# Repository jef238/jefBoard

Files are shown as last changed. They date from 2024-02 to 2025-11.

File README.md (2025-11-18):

# jefBoard
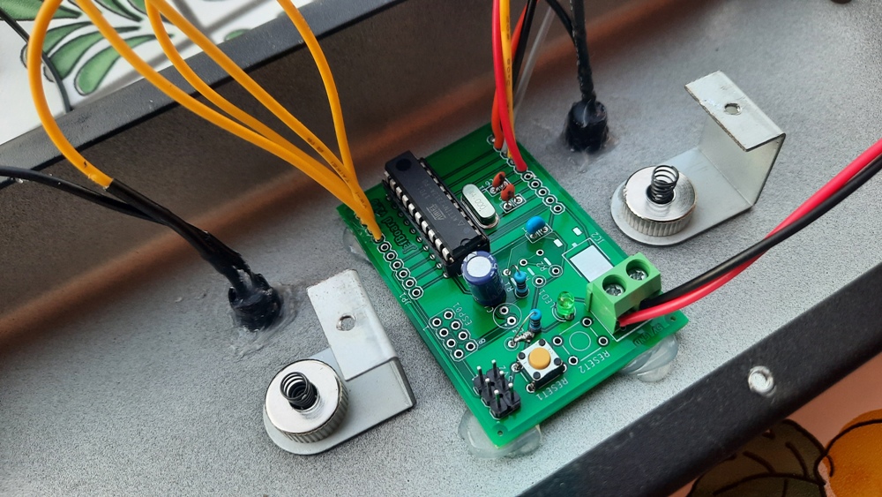
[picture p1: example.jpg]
example

## Cos'è

JefBoard è una scheda di sviluppo basata sul microcontroller Attiny2313 della ATMEL. Si presta allo sviluppo di applicazioni di varia natura e integra la predisposizione per la scheda WiFI ESP-01 (Opzionale) e il connettore per la programmazione ISP dell'Attiny2313.
Alcune caratteristiche:
- JefBoard espone tutti i pin dell'Attiny2313 per il loro utilizzo.
- JefBoard permette la realizzazione di applicazioni con supporto WiFi (il modulo ESP-01 comunica tramite connessione seriale con l'Attiny2313).
- JefBoard può essere assemblata anche senza l'ESP-01 e relativi componenti di alimentazione se non si necessita di supporto WiFi abbassando ulteriormente il costo.
- JefBoard è una scheda di piccole dimensioni 6x4 cm.

## Attiny 2313 pinout

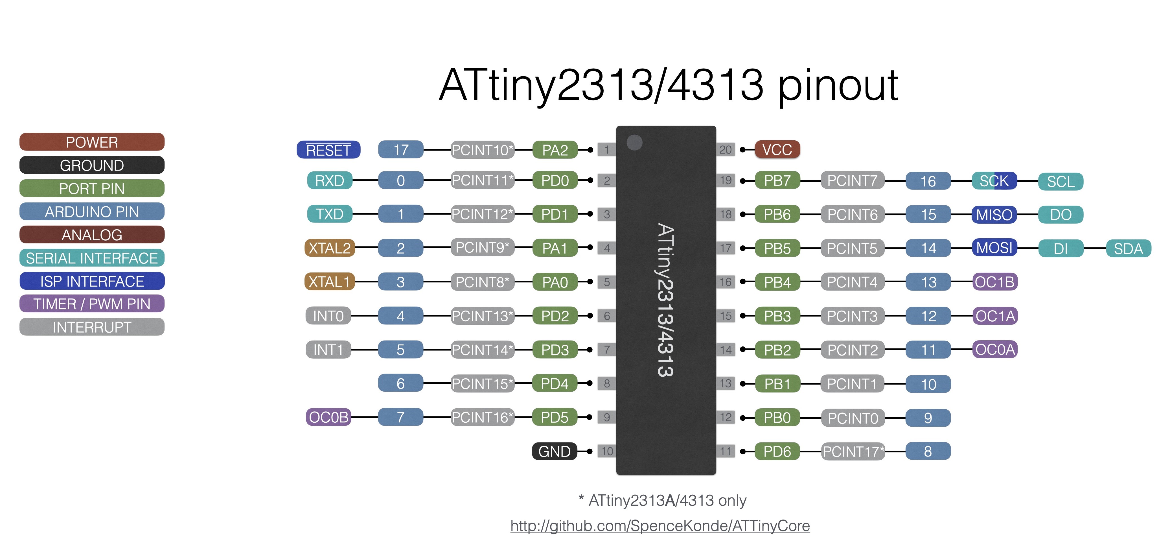
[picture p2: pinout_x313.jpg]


# Schema ed elenco componenti

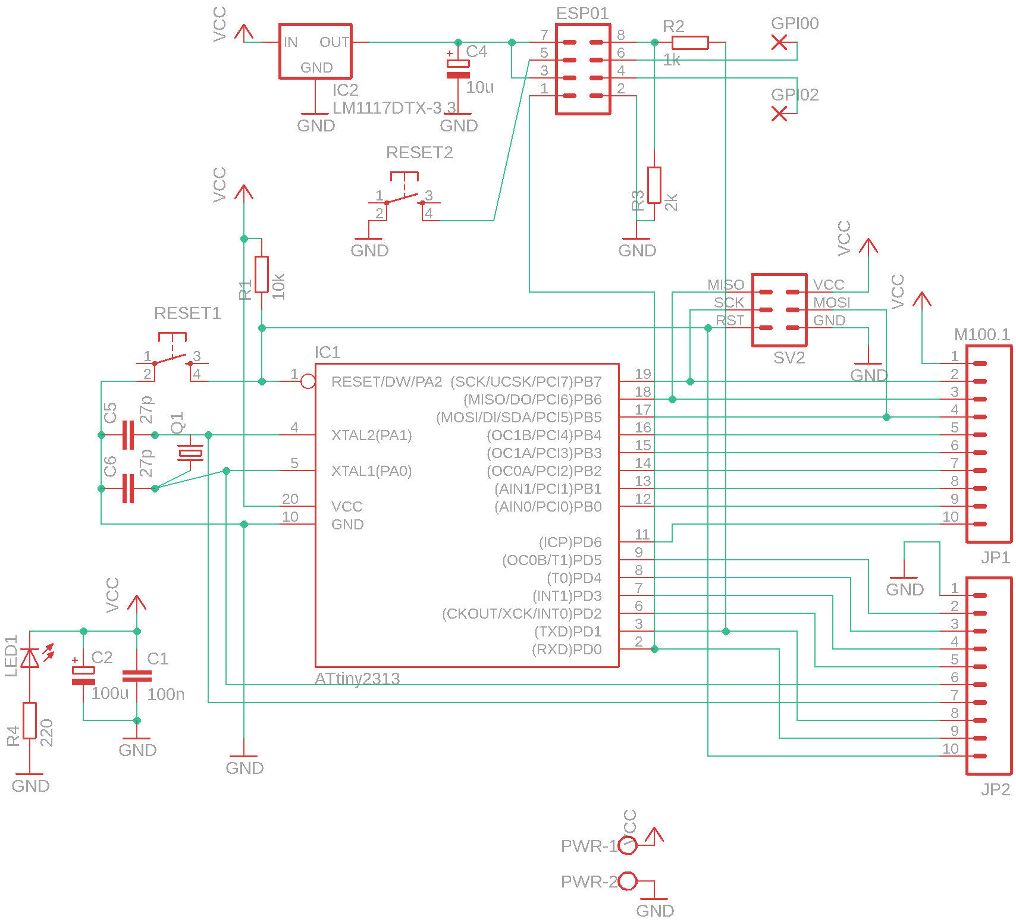
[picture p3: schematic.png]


# PCB Layout
Per reperire la PCB scrivi al mio indirizzo giuseppe.culotta@gmail.com

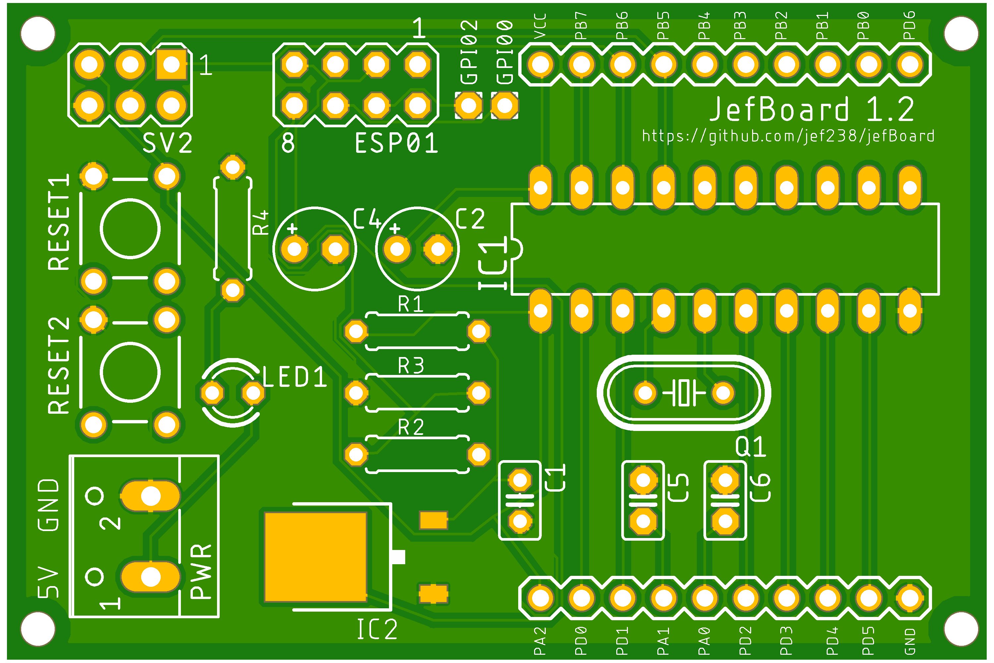
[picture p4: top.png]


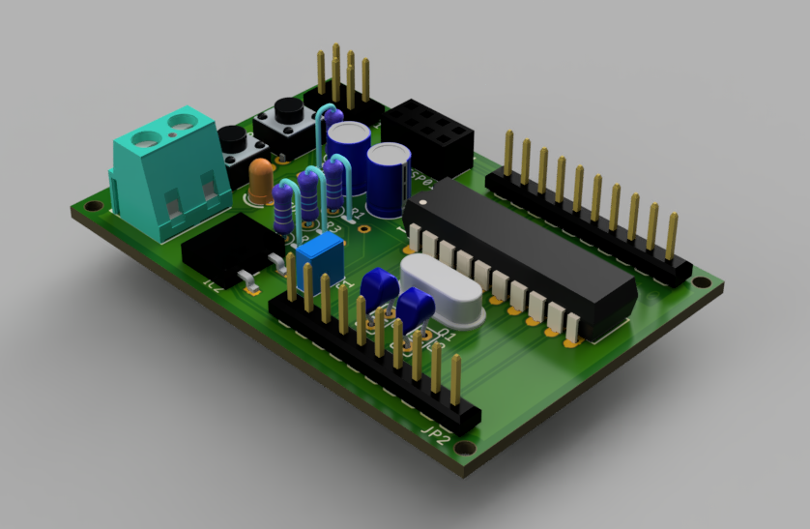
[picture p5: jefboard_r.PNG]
jefboard_r


## Elenco componenti

| Sigla | Valore | Tipo			 | Note |
|---|---|---|---|
| C1 | 100n 		| Condensatore poliestere |				 | 
| C2 | 100u 		| Condensatore elettrolitico |					 |
| C4 | 10u 		| Condensatore elettrolitico | (Opzionale - Solo in caso di supporto WIFI) |	
| C5 | 22p 		| Condensatore ceramico |					 |
| C6 | 22p 		| Condensatore ceramico | 					 |
| ESP01 | 		| Connettore pin		| (Opzionale - Solo in caso di supporto WIFI) |
| IC1 | ATtiny2313/ATtiny2313a | AVR			 |				 |
| IC2 | LM1117DTX 3.3V 		|			 | (Opzionale - Solo in caso di supporto WIFI) |	
| JP1 | 		| Connettore tipo M100.1	| (Opzionale) 		 |
| JP2 | 		| Connettore tipo M100.1	| (Opzionale) |
| LED1  | 		| LED3MM |				 |
| PWR | 		| Connettore tipo W237-102 | (Opzionale) |
| Q1 | 		| Quarzo 4MHZ 	 |	 |
| R1 | 10k 		| 1/4w		 | |
| R2 | 1k 		| 1/4w 				| (Opzionale - Solo in caso di supporto WIFI) |	
| R3 | 2k 		| 1/4w 	 		| (Opzionale - Solo in caso di supporto WIFI) |	
| R4 | 220 		| 1/4w 		| 					 |
| RESET1| 		| Microswitch | |
| RESET2| 		| Microswitch			| (Opzionale - Solo in caso di supporto WIFI) |
| SV2 | 		| Connettore pin | |
         
# Programmazione

Io utilizzo Xcode e [CrossPack for AVR Development](https://github.com/obdev/CrossPack-AVR) in ambiente Mac.

In ambiente Windows vi consiglio di utilizzare Atmel Studio 7 ma sembra che recentemente sia stato sostituito da un altro prodotto: https://www.microchip.com/en-us/tools-resources/develop/microchip-studio.
Se utilizzate Atmel Studio ricordate di selezionare l'Attiny2313a come chip durante la creazione del progetto ed eseguire i seguenti step:
- Project->Properties->Toolchain->AVR/GNU C Compiler->Symbols: aggiungere F_CPU=2000000  (In questo caso la frequenza di clock è di 2MHZ)
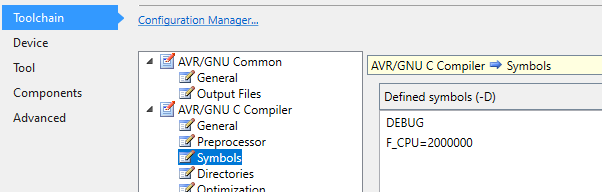
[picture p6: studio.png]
atstudio

- Impostare USBTINY come external tool (https://www.programming-electronics-diy.xyz/2020/09/using-usbtinyisp-programmer-with-atmel.html), in questo modo potete scrivere il firmware in formato hex sul chip direttamente dall'interfaccia di Atmel Studio dal menu Tools.

Come programmatore hardware per l'ISP ho utilizzato l'USBtinyISP:

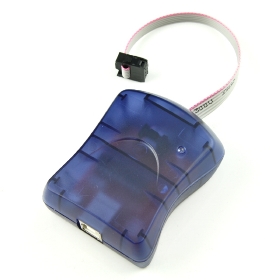
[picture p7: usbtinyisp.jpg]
usbtinyisp


## 1. Impostazione FUSE bits

Questa procedura deve essere eseguita solo una volta poichè serve a settare le impostazioni di base del bootloader del chip   

- Utilizzare AVR Calculator per ottenere la stringa corretta (http://www.engbedded.com/fusecalc)

    ESEMPI:
    ```
    /* Oscillatore interno 1MHZ */     						-U lfuse:w:0x64:m -U hfuse:w:0xdf:m -U efuse:w:0xff:m
    /* Quarzo esterno da 3 a 8MHZ */   						-U lfuse:w:0xfd:m -U hfuse:w:0xdf:m -U efuse:w:0xff:m
    /* Quarzo esterno da 16MHZ con CKDIV8 e frequenza effettiva 2MHZ */		-U lfuse:w:0x5e:m -U hfuse:w:0xdf:m -U efuse:w:0xff:m     
    ```
- Impostare i FUSE Bits nell'Attiny2313:
   ```
   avrdude -c usbtiny -p t2313 -e -U lfuse:w:0xfd:m -U hfuse:w:0xdf:m -U efuse:w:0xff:m
   ```

## 2a. Compilazione su Xcode (Mac)

- Modificare le righe seguenti nel file Makefile (ATTENZIONE: la riga FUSES deve essere identica alle impostazioni di FUSE Bits dell'Attiny2313; in questo esempio si utilizza un quarzo esterno da 4MHZ):
	```
	DEVICE     = attiny2313
	CLOCK      = 4000000
	PROGRAMMER = -c usbtiny -p attiny2313
	OBJECTS    = main.o
	FUSES      = -U lfuse:w:0xFD:m -U hfuse:w:0xDF:m -U efuse:w:0xFF:m -U lock:w:0xFF:m
  ```
- effettuare build (verrà generato main.hex)

## 2b. Compilazione su Atmel Studio (Windows)

- Menu Build->Build "nome progetto"
                                                             
## 3. Collegare l'USBtinyISP

- Assicurarsi di aver correttamente collegato il programmatore al computer e di aver installato i driver per il suo funzionamento (su Mac non è necessario installare driver)

- Collegare l'USBtinyISP al connettore SV2

## 4a. Flash su Mac

- Caricare il file .hex nel chip: 
   ```
   avrdude -c usbtiny -p t2313 -e -U flash:w:main.hex
   ```
## 4b. Flash su Windows (Atmel Studio)

- Menu Tools->USBTiny (per la configurazione vedi https://www.programming-electronics-diy.xyz/2020/09/using-usbtinyisp-programmer-with-atmel.html)

# Utilizzo dell'ESP01 per il supporto WIFI

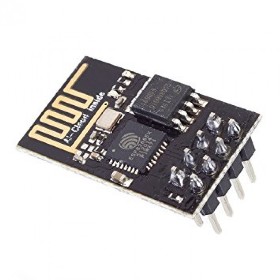
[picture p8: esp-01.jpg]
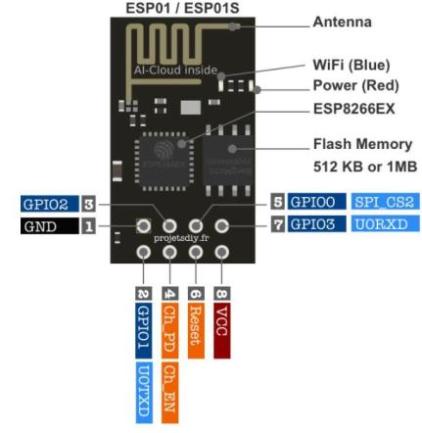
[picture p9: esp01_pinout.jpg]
  

L'ESP01 è un modulo SOC basato sul chip ESP8266 che permette di aggiungere il supporto al WIFI in modo semplice ed economico.
Prima di inserirlo sulla jefBoard è necessario fare una precisazione:
L'ESP01 viene fornito generalmente con un firmware dotato di soli comandi AT per cui prima di utilizzarlo nei nostri progetti è necessario caricare il firmware nodeMCU (https://it.wikipedia.org/wiki/NodeMCU). Con questo firmware è possibile programmare facilmente l'ESP01 tramite linguaggio LUA ed è possibile compilare una versione custom di nodeMCU con il supporto delle librerie/funzionalità necessarie in base all'utilizzo su https://nodemcu-build.com.

E' necessario inoltre dotarsi di un adattore USB seriale TTL:

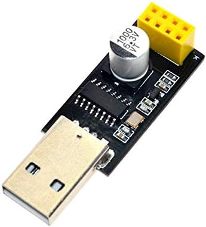
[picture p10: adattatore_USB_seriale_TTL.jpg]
adattatore


## Istruzioni per l’installazione di esptool su MACOSX:

- Scaricare e scompattare esptool (https://github.com/espressif/esptool)

- Assicurarsi di avere Python 1.7 o successivo installato sul sistema

- Spostarsi sulla directory appena scompattata ed eseguire:
   ```
   sudo python setup.py install
   ```

## Istruzioni per flash nodemcu su ESP01
Esistono tanti modi per abilitare la modalità flash su ESP-01 (una ricerca su google è altamente consigliata...). Tempo fa ho realizzato una scheda che per comodità mi permette di riavviare tramite reset l'ESP01 (pulsante 1) mentre metto a massa il pin GPIO0 (pulsante 2):

- Posizionare l’ESP01 e l’interfaccia seriale/USB sulla scheda di programmazione:

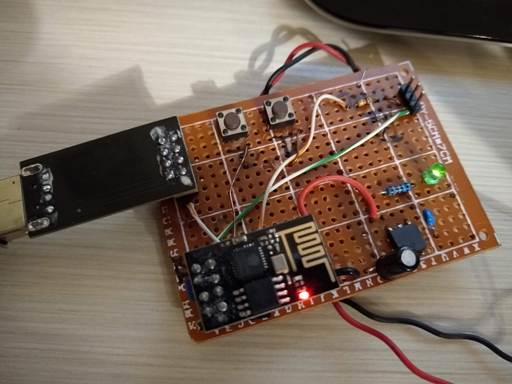
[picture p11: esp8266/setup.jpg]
  

- Per settare l’ESP01 in modalità flash tenere premuto il pulsante 2 e contemporaneamente effettuare un reset premendo e rilasciando il pulsante 1; dopo qualche istante rilasciare il pulsante 2.

- Effettuare il comando (nodemcu_base_int.bin è il nome del file del firmware nodemcu da flashare vedi cartella esp8266):
   ```  
   python esptool.py --port /dev/tty.wchusbserialfa140 write_flash 0x00000 nodemcu_base_int.bin
   ```
- (opzionale) restore firmware originale (11/12/2019)
   ``` 
   python esptool.py --port /dev/tty.wchusbserialfd130 write_flash 0x00000 v0.9.2.2\ AT\ Firmware.bin
   ``` 
## Programmazione ESP01 tramite script LUA
Una volta caricato il firmware nodeMCU è possibile caricare gli script LUA. Il file denominato init.lua viene caricato all'avvio in maniera automatica.
E' possibile utilizzare il software ESPlorer (https://github.com/4refr0nt/ESPlorer) sia per caricare sia gli script LUA che per gestire al meglio l'ESP01.

# Utilizzo di jefBoard come server WIFI
In questo caso l'ESP01 funge da server in ascolto sulla porta 8080 tramite connessione WIFI; Ricevuto il comando lo inoltra tramite la connessione seriale verso l'Attiny2313.
Per questo utilizzo è necessario che la scheda sia equipaggiata con l'ESP01 aggiornata con il firmware nodeMCU, ed i relativi componenti. Di seguito un esempio di file init.lua (da caricare sull'ESP01) e del codice da utilizzare sull'Attiny2313:

## init.lua (ESP01)

```
wifi.setmode(wifi.SOFTAP)
cfg={}
cfg.ssid="jefBoard"
wifi.ap.config(cfg)

uart.setup(0, 9600, 8, uart.PARITY_NONE, uart.STOPBITS_1, 1)

sv = net.createServer(net.TCP, 30)

function receiver(sck, data)
  print(data)  --senda data to jefBoard by serial
end

if sv then
  sv:listen(8080, function(conn)
    conn:on("receive", receiver)    
  end)
end
```

## main.c (jefBoard/Attiny2313)

```
#define F_CPU 4000000 UL // 4 MHz Crystal

#include <avr/io.h>
#include <util/delay.h>
#include <avr/interrupt.h>

// Define baud rate
#define USART_BAUDRATE 9600
#define BAUD_PRESCALE (((F_CPU / (USART_BAUDRATE * 16UL))) - 1)

volatile unsigned char value;
/* This variable is volatile so both main and RX interrupt can use it.
 It could also be a uint8_t type */

/* Interrupt Service Routine for Receive Complete
 NOTE: vector name changes with different AVRs see AVRStudio -
 Help - AVR-Libc reference - Library Reference - <avr/interrupt.h>: Interrupts
 for vector names other than USART_RX_vect for Attiny2313 */

void dosomething(); //Exec something

void USART_Init(void) {
  // Set baud rate
  UBRRL = BAUD_PRESCALE; // Load lower 8-bits into the low byte of the UBRR register
  UBRRH = (BAUD_PRESCALE >> 8);
  /* Load upper 8-bits into the high byte of the UBRR register
   Default frame format is 8 data bits, no parity, 1 stop bit
   to change use UCSRC, see AVR datasheet*/

  // Enable receiver and transmitter and receive complete interrupt
  UCSRB = ((1 << TXEN) | (1 << RXEN) | (1 << RXCIE));
}

void USART_SendByte(uint8_t u8Data) {

  // Wait until last byte has been transmitted
  while ((UCSRA & (1 << UDRE)) == 0);

  // Transmit data
  UDR = u8Data;
}

// not being used but here for completeness
// Wait until a byte has been received and return received data
uint8_t USART_ReceiveByte() {
  while ((UCSRA & (1 << RXC)) == 0);
  return UDR;
}

ISR(USART_RX_vect) {
  if (UDR != 0x0A) value = UDR; //read UART register into value except <RETURN> key
}

void dosomething() {
  //Exec something    
}

int main(void) {

  USART_Init(); // Initialise USART
  sei(); // enable all interrupts

  //If received data from serial match 'd' char exec dosomething() function
  while (1) {
    if (value == 0x64) dosomething(); //ASCII for 'd'     
  }

  return 0;
}
``` 
## Contatti

giuseppe.culotta@gmail.com

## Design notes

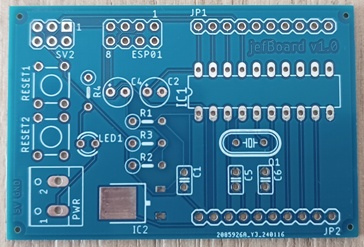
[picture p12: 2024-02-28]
pcb.jpg

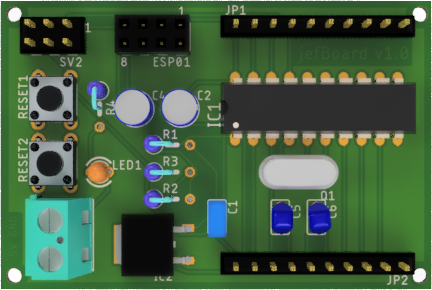
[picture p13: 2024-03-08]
jefboard_top.png

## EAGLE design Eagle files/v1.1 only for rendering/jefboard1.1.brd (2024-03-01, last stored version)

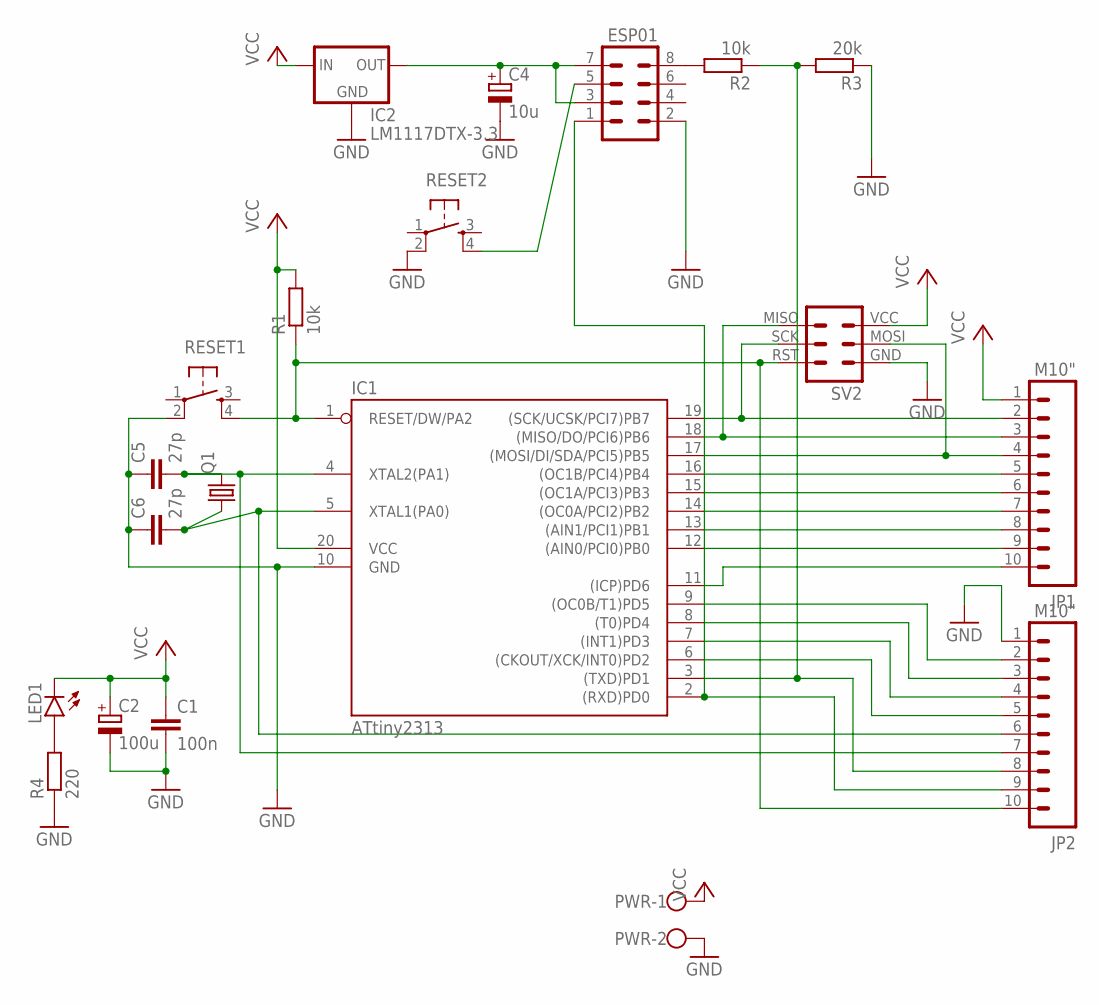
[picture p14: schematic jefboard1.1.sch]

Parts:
C1: 100n; C025-025X050
C2: 100u; E2,5-5
C4: 10u; E2,5-5
C5, C6: 27p; C2.5-2
ESP01: MA04-2
IC1: ATtiny2313; DIL20
IC2: LM1117DTX-3.3; TO252
JP1, JP2: M10"; 1X10
LED1: LED3MM
PWR: W237-102
Q1: CRYSTALHC49S; HC49/S
R1, R2: 10k; 0207/5V
R3: 20k; 0207/5V
R4: 220; 0207/5V
RESET1, RESET2: TAC_SWITCHPTH; TACTILE-PTH
SV2: MA03-2

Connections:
GND: C1.2, C2.-, C4.-, C5.1, C6.1, ESP01.2, IC1.10 (GND), IC2.1 (GND), JP2.1, PWR.2, R3.1, R4.1, RESET1.2, RESET2.2, SV2.GND
unnamed: C4.+, ESP01.3, ESP01.7, IC2.TAB (OUT)
unnamed: C5.2, IC1.4 (XTAL2(PA1)), JP2.7, Q1.2
unnamed: C6.2, IC1.5 (XTAL1(PA0)), JP2.6, Q1.1
unnamed: IC1.1 (RESET/DW/PA2), JP2.10, R1.1, RESET1.4, SV2.RST
unnamed: IC1.19 ((SCK/UCSK/PCI7)PB7), JP1.2, SV2.SCK
unnamed: IC1.18 ((MISO/DO/PCI6)PB6), JP1.3, SV2.MISO
unnamed: IC1.17 ((MOSI/DI/SDA/PCI5)PB5), JP1.4, SV2.MOSI
unnamed: IC1.16 ((OC1B/PCI4)PB4), JP1.5
unnamed: IC1.15 ((OC1A/PCI3)PB3), JP1.6
unnamed: IC1.14 ((OC0A/PCI2)PB2), JP1.7
unnamed: IC1.13 ((AIN1/PCI1)PB1), JP1.8
unnamed: IC1.12 ((AIN0/PCI0)PB0), JP1.9
unnamed: IC1.11 ((ICP)PD6), JP1.10
unnamed: IC1.9 ((OC0B/T1)PD5), JP2.2
unnamed: IC1.8 ((T0)PD4), JP2.3
unnamed: IC1.7 ((INT1)PD3), JP2.4
unnamed: IC1.6 ((CKOUT/XCK/INT0)PD2), JP2.5
unnamed: IC1.3 ((TXD)PD1), JP2.8, R2.1, R3.2
unnamed: ESP01.5, RESET2.4
unnamed: ESP01.8, R2.2
unnamed: LED1.A, R4.2
RX: ESP01.1, IC1.2 ((RXD)PD0), JP2.9
VCC: C1.1, C2.+, IC1.20 (VCC), IC2.2 (IN), JP1.1, LED1.K (C), PWR.1, R1.2, SV2.VCC

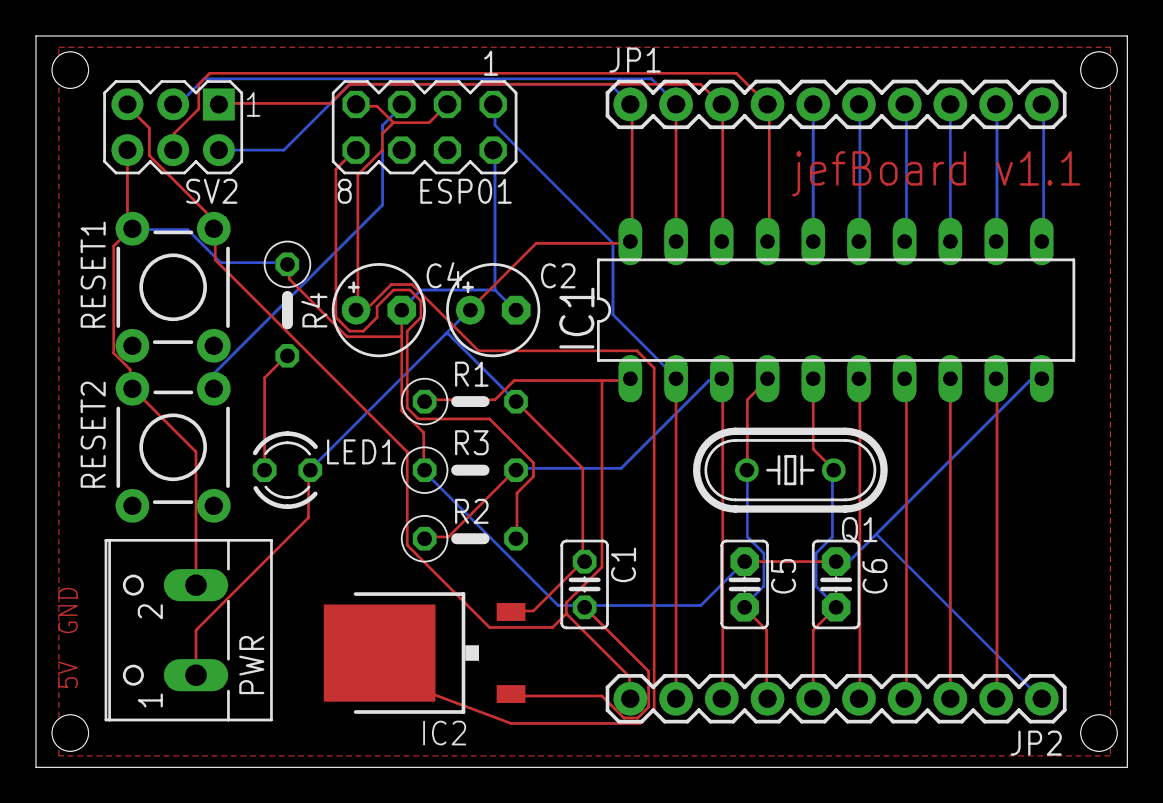
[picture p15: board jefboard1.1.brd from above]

Board: 2 copper layers, 60.6 x 40.6 mm, 20 parts (0 on the bottom side), 24 nets.

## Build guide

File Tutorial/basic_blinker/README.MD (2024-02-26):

# Basic Blinker
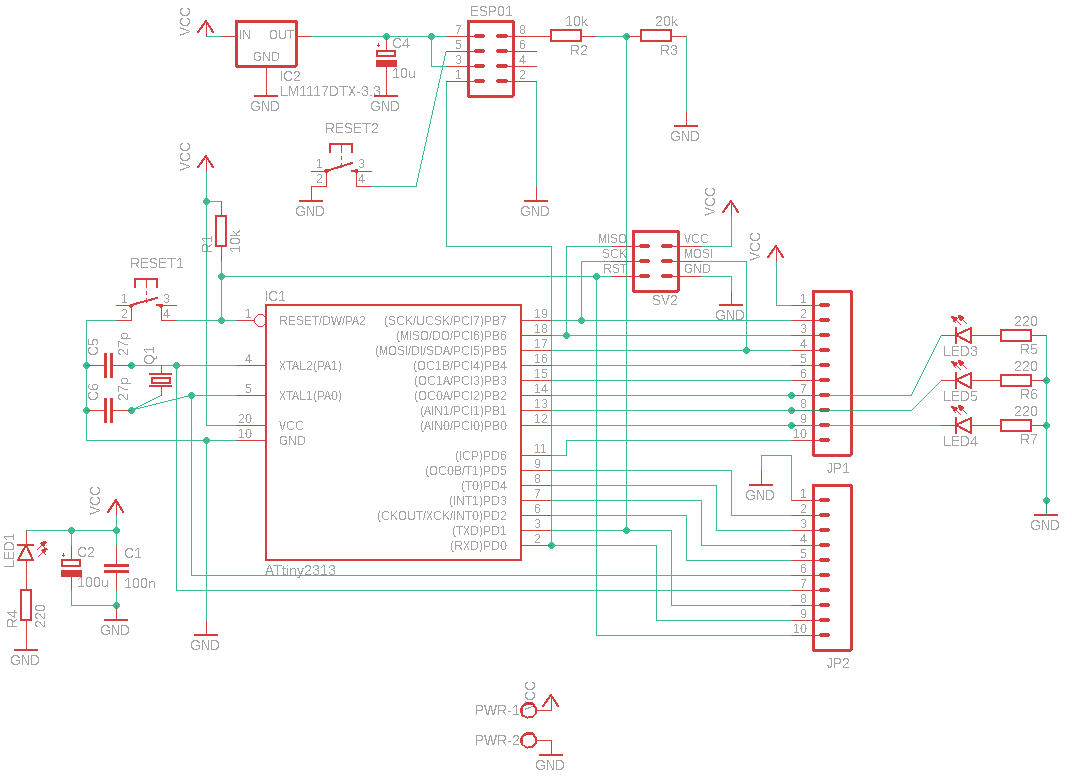
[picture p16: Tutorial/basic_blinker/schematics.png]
example


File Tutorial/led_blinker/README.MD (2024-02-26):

# Led Blinker
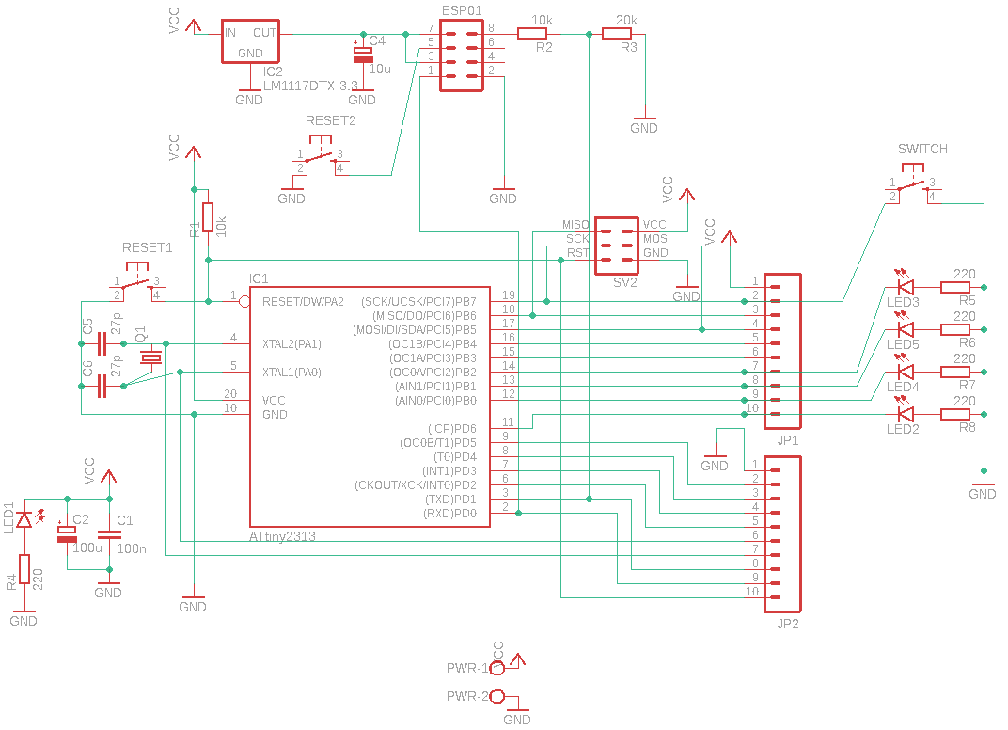
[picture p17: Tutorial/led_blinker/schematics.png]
example


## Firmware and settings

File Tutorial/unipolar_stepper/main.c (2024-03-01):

/* Name: main.c
 * Author: g.culotta 
 */

#include <avr/io.h>
#include <util/delay.h>

void myDelay();
void up();
void down();

int main(void)
{

    DDRB |= (1 << PB2) | (1 << PB1) | (1 << PB0); //Setup as output
    DDRD |= 1 << PD6; //Setup as output
    
    DDRD &= ~(1 << PD5); //Setup as input
    PORTD |= (1 << PD5); //Enable pullup resistor
    
    #define A_on  PORTB |= (1 <<  PB2);
    #define B_on  PORTB |= (1 <<  PB1);
    #define C_on  PORTB |= (1 <<  PB0);
    #define D_on  PORTD |= (1 <<  PD6);
    #define A_off  PORTB &= ~(1 <<  PB2);
    #define B_off  PORTB &= ~(1 <<  PB1);
    #define C_off  PORTB &= ~(1 <<  PB0);
    #define D_off  PORTD &= ~(1 <<  PD6);
    

    while(1){
        if (PIND & (1 << PD5)) {    // is switch open?
            // switch is open...            
        }
        else {
            // switch is closed...
            up();
        }
    }
    
    return 0;
}

void myDelay(){
    _delay_ms(5);
}

void up(){
    A_on;
    B_on;
    myDelay();
    A_off;
    B_on;
    C_on;
    myDelay();
    B_off;
    C_on;
    D_on;
    myDelay();
    C_off;
    D_on;
    A_on;
    myDelay();
    D_off;
    A_off;
}

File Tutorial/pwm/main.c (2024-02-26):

// TC0_fast_PWM.c
#define F_CPU 4000000UL
#include <avr/io.h>
#include <util/delay.h>

int main(void)
{
    unsigned char PWM_val1 = 0;        // 8-bit PWM value
    unsigned char PWM_val2 = 255;      // 8-bit PWM value
    unsigned char up_dn = 0;           // up down count flag
    
    DDRB   |= (1 << PB2);              // PWM output on PB2 - OC0A
    DDRD   |= (1 << PD5);              // PWM output on PD5 - OC0B
    // fast PWM mode
    TCCR0A = (1 << COM0A1) | (1 << COM0B1) | (1 << WGM01) | (1 << WGM00);
    TCCR0B = (1 << CS01);   // clock source = CLK/8, start PWM
    
    while(1)
    {
        if ((PWM_val1 == 255) || (PWM_val1 == 0)) {
            up_dn ^= 0x01;      // toggle count direction flag
        }
        _delay_ms(5);
        OCR0A  = PWM_val1;       // write new PWM value
        OCR0B  = PWM_val2;
        if (up_dn) {            // increment or decrement PWM value
            PWM_val1++;
            PWM_val2--;
        }
        else {
            PWM_val1--;
            PWM_val2++;
        }
    }
}

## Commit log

2025-11-18 Update resistor values for WIFI support
2025-11-18 Remove PCB image from README
    Removed the PCB image from the README.
